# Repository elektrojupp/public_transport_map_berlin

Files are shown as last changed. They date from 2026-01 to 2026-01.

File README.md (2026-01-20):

# Public Transport Map of Berlin

There are some commercial maps of similar design out there. They mostly use multiple LEDs per station and show less complexity by splitting services into separate maps.

This project shows the complete maps for Berlin’s suburban rail and subway. It uses 312 NeoPixel-compatible RGB LEDs for 314 stations on a two-layer board. A standard ESP32 dev module is used to get live transport data. It will be replaced by a board supporting PSRAM for flexibility.

## PCB Design

The PCB design is done in KiCad 9. It uses SK6805-EC10-000 NeoPixel-compatible LEDs by OPSCO connected in one non-intersecting path.

The LEDs are only 1.1×1.1 mm in size and can be sourced from JLCPCB for PCB manufacturing and assembly.

The current PCB size is 153×107 mm, which is roughly the size of a DIN A6 sheet.

It is an improved but untested version of the original test design.

Scaling of the PCB can be done with a Python script. It includes automatic placement of the LEDs and routing in between. The scaled version only needs adjustment of the text size and placement of the ESP32 dev module connector.

## Software

The software is developed using VS Code, PlatformIO, and ESP-IDF. It is not documented, but the project can be compiled if you have a working setup.

It uses the REST API from derhuerst <https://github.com/derhuerst/bvg-rest> to get information about active rides on a certain suburban or subway line and displays the station where the train arrives next. It currently supports displaying only one line at a time due to a memory shortage.

### Features

- provisioning
- HTTP OTA server
- capacitive touch
- NeoPixel LED control
- display live train data

The HTTP OTA server is not secure and allows anyone to upload any firmware. It can be enabled by touching the "O" button during the startup sequence (blue blinking status LEDs). Similarly, provisioning data also gets removed.

## Scaling

The PCB has been designed to be minimal in size to reduce manufacturing cost. It can be scaled using the KiCad IPC API. This requires KiCad 9 and above. The IPC API has some quirks, but first it needs to be enabled in the KiCad settings.

## Pictures
Showing the actual version of the PCB:  

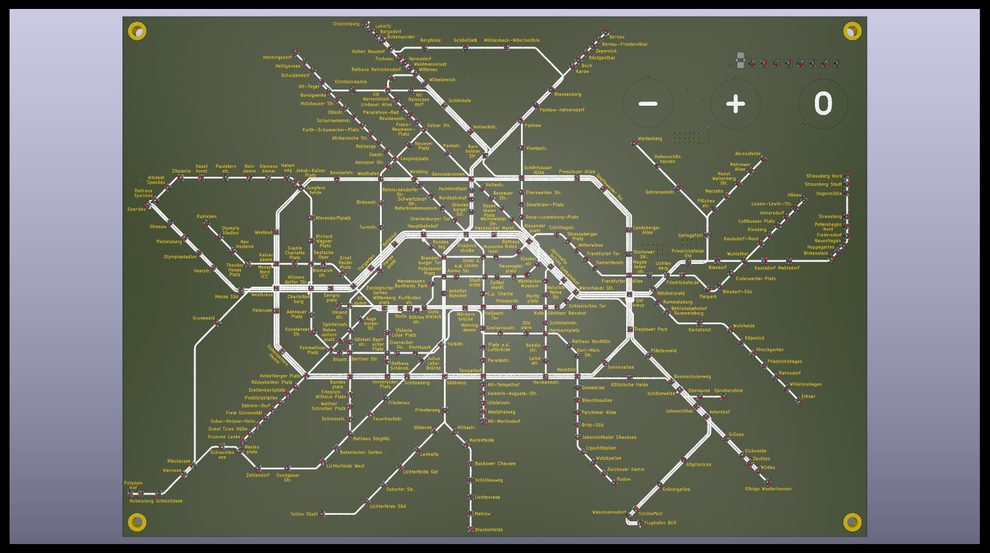
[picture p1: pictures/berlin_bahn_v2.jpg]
Berlin Bahn v2

V1 manufactured  

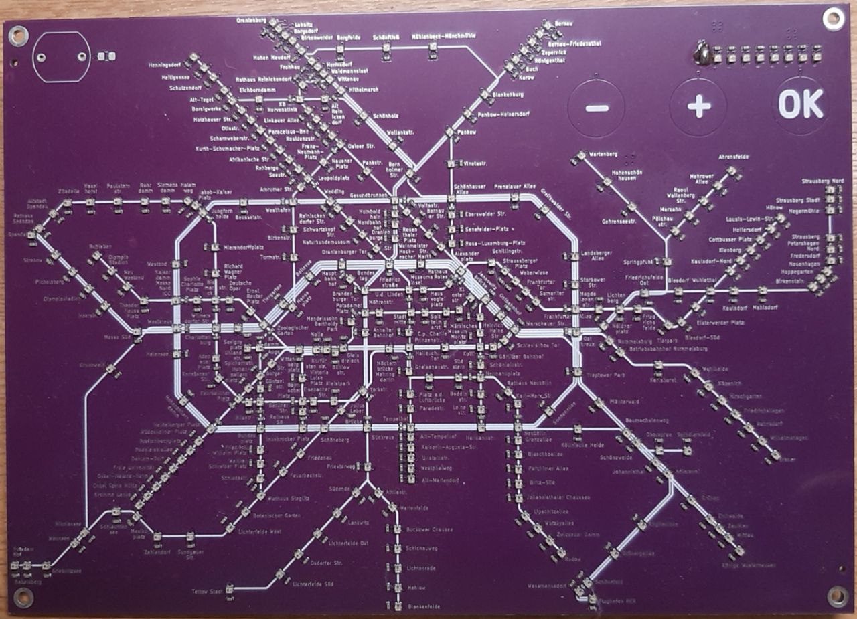
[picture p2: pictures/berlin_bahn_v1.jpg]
Berlin Bahn v1


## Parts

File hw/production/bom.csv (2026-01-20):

Designator | Footprint | Quantity | Value | LCSC Part #
C1, C10, C100, C101, C102, C103, C104, C105, C106, C107, C108, C109, C11, C110, C111, C112, C113, C114, C115, C116, C117, C118, C119, C12, C120, C121, C122, C123, C124, C125, C126, C127, C128, C129, C13, C130, C131, C132, C133, C134, C135, C136, C137, C138, C139, C14, C140, C141, C142, C143, C144, C145, C146, C147, C148, C149, C15, C150, C151, C152, C153, C154, C155, C156, C157, C158, C159, C16, C160, C161, C162, C163, C164, C165, C166, C167, C168, C169, C17, C170, C171, C172, C173, C174, C175, C176, C177, C178, C179, C18, C180, C181, C182, C183, C184, C185, C186, C187, C188, C189, C19, C190, C191, C192, C193, C194, C195, C196, C197, C198, C199, C2, C20, C200, C201, C202, C203, C204, C205, C206, C207, C208, C209, C21, C210, C211, C212, C213, C214, C215, C216, C217, C218, C219, C22, C220, C221, C222, C223, C224, C225, C226, C227, C228, C229, C23, C230, C231, C232, C233, C234, C235, C236, C237, C238, C239, C24, C240, C241, C242, C243, C244, C245, C246, C247, C248, C249, C25, C250, C251, C252, C253, C254, C255, C256, C257, C258, C259, C26, C260, C261, C262, C263, C264, C265, C266, C267, C268, C269, C27, C270, C271, C272, C273, C274, C275, C276, C277, C278, C279,C28, C280, C281, C282, C283, C284, C285, C286, C287, C288, C289, C29, C290, C291, C292, C293, C294, C295, C296, C297, C298, C299, C3, C30, C300, C301, C302, C303, C304, C305, C306, C307, C308, C309, C31, C310, C311, C312, C313, C314, C315, C316, C317, C318, C319, C32, C320, C33, C34, C35, C36, C37, C38, C39, C4, C40, C4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 | 0402 | 200 | 100n | C1525
U1, U10, U100, U101, U102, U103, U104, U105, U106, U107, U108, U109, U11, U110, U111, U112, U113, U114, U115, U116, U117, U118, U119, U12, U120, U121, U122, U123, U124, U125, U126, U127, U128, U129, U13, U130, U131, U132, U133, U134, U135, U136, U137, U138, U139, U14, U140, U141, U142, U143, U144, U145, U146, U147, U148, U149, U15, U150, U151, U152, U153, U154, U155, U156, U157, U158, U159, U16, U160, U161, U162, U163, U164, U165, U166, U167, U168, U169, U17, U170, U171, U172, U173, U174, U175, U176, U177, U178, U179, U18, U180, U181, U182, U183, U184, U185, U186, U187, U188, U189, U19, U190, U191, U192, U193, U194, U195, U196, U197, U198, U199, U2, U20, U200, U201, U202, U203, U204, U205, U206, U207, U208, U209, U21, U210, U211, U212, U213, U214, U215, U216, U217, U218, U219, U22, U220, U221, U222, U223, U224, U225, U226, U227, U228, U229, U23, U230, U231, U232, U233, U234, U235, U236, U237, U238, U239, U24, U240, U241, U242, U243, U244, U245, U246, U247, U248, U249, U25, U250, U251, U252, U253, U254, U255, U256, U257, U258, U259, U26, U260, U261, U262, U263, U264, U265, U266, U267, U268, U269, U27, U270, U271, U272, U273, U274, U275, U276, U277, U278, U279,U28, U280, U281, U282, U283, U284, U285, U286, U287, U288, U289, U29, U290, U291, U292, U293, U294, U295, U296, U297, U298, U299, U3, U30, U300, U301, U302, U303, U304, U305, U306, U307, U308, U309, U31, U310, U311, U312, U313, U314, U315, U316, U317, U318, U319, U32, U320, U33, U34, U35, U36, U37, U38, U39, U4, U40, U4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 | SMD-4P,1.1x1.1mm | 200 | XL-1010RGBC-WS2812B | C5349953

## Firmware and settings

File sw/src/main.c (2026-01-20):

#include "esp_system.h"
#include "esp_log.h"
#include "nvs_flash.h"
#include "esp_netif.h"
#include "esp_event.h"

#include "cap_touch.h"
#include "led.h"
#include "line_state.h"
#include "time_server.h"
#include "tripring.h"
#include "requests.h"
#include "provisioning.h"

//static const char * TAG = "APP_INIT";

static void cap_touch_task(void *pvParameters)
{
    // the first one runs until the init sequence is completed
    // enables to possibility to restart provisioning
    cap_touch_check();
    cap_touch_run();
}
static void led_task(void *pvParameters)
{
    display_chance_to_reset_provisioning_pattern();
    fiddle_as_lon_as_init();
    led_stripe_run();
}

static void http_request_task(void *pvParameters)
{
    BVG_run();
}


void app_main() 
{
    esp_log_level_set("esp-x509-crt-bundle", ESP_LOG_ERROR);
    esp_log_level_set("BVG_FETCHER", ESP_LOG_VERBOSE);
    
    line_state_init();
    line_state_set_init_mode();
    led_stripe_init();
    cap_touch_init();
    tr_init();

    // got into the check if provisioning can be reset mode
    line_state_set_reset_provisioning_mode();
    xTaskCreatePinnedToCore(cap_touch_task, "cap_touch_task", 4096, NULL, 5, NULL, 1);

    xTaskCreatePinnedToCore(cap_touch_task, "cap_touch_task", 4096, NULL, 5, NULL, 1);
    xTaskCreatePinnedToCore(http_request_task, "http_request_task", 8192, NULL, 5, NULL, 0);
    xTaskCreatePinnedToCore(led_task, "led_task", 4096, NULL, 5, NULL, 1);

    // wait init sequence
    vTaskDelay(pdMS_TO_TICKS(3000));
    line_state_release_reset_provisioning_mode();

    // wait for 3 seconds while displaying key pattern to indicate that credentials can be deleted
    bool reset = cap_touch_check_is_pressed();
    provisioning(reset);
    
    time_server();
    print_time();

    line_state_release_init_mode();
}

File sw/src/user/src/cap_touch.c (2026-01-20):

#include <stdio.h>
#include <inttypes.h>
#include "freertos/FreeRTOS.h"
#include "freertos/task.h"
#include "esp_log.h"
#include "esp_timer.h"
#include "driver/touch_sens.h"
#include "line_state.h"
#include "line_data.h"

typedef enum {
    TSTATE_RELEASED = 0,
    TSTATE_PENDING_ACTIVE,
    TSTATE_ACTIVE,
    TSTATE_PENDING_RELEASE
} tstate_t;

typedef struct {
    touch_channel_handle_t ch;
    uint32_t               baseline;
    uint32_t               thresh_abs;       // V1 uses absolute threshold (baseline * (1 - ratio))
    tstate_t               st;
    int64_t                dwell_start_us;
} tdebounce_t;

#define TOUCH_NUM_CHANNELS       3
#define TOUCH_THRESH_RATIO       0.20f   // trigger when value drops 20% from baseline
#define TOUCH_ACTIVE_DWELL_MS    60      // must stay below threshold this long to count as "touched"
#define TOUCH_RELEASE_DWELL_MS   60      // must stay above threshold this long to count as "released"
#define TOUCH_POLL_PERIOD_MS     10      // sampling period of the poll task

/*
   T0=GPIO4,  T1=GPIO0,  T2=GPIO2,  T3=GPIO15, T4=GPIO13,
   T5=GPIO12, T6=GPIO14, T7=GPIO27, T8=GPIO33, T9=GPIO32   */
static const int s_touch_chan_ids[TOUCH_NUM_CHANNELS] = { 0, 3, 6};

static touch_sensor_handle_t s_touch = NULL;
static tdebounce_t s_db[TOUCH_NUM_CHANNELS] = {0};

// pressed is used to indicate if some button has been pressed and released during the initalization phase
// and to check weather or not delete previously saved wifi credentials
uint32_t check_pressed = 0;

static const char *TAG = "CAPACITIVE_TOUCH";

void on_touch(int chan_id) {
    if (chan_id == 3) {
        (void)line_state_add_wrap(+1, 0, line_data_number_of_lines()-1);
    } else if (chan_id == 0) {
        (void)line_state_add_wrap(-1, 0, line_data_number_of_lines()-1);
    }
    line_state_set_pressed(true);
    line_state_t s;
    line_state_get(&s);
    ESP_LOGI(TAG, "line = %d pressed = %d, channel = %d", s.line, s.pressed, chan_id);
}

void on_release(int chan_id) {
    line_state_set_pressed(false);
    line_state_t s;
    line_state_get(&s);
    ESP_LOGI(TAG, "line = %d, pressed = %d, channel = %d", s.line, s.pressed, chan_id);
}

void cap_touch_init(void)
{
    ESP_LOGI(TAG, "INIT");
    ESP_LOGI(TAG, "Channels = T%d, T%d, T%d", s_touch_chan_ids[0], s_touch_chan_ids[1], s_touch_chan_ids[2]);

    touch_sensor_sample_config_t sample_cfg[] = {
        TOUCH_SENSOR_V1_DEFAULT_SAMPLE_CONFIG(5.0, TOUCH_VOLT_LIM_L_0V5, TOUCH_VOLT_LIM_H_1V7),
    };
    touch_sensor_config_t sens_cfg = TOUCH_SENSOR_DEFAULT_BASIC_CONFIG(1, sample_cfg);
    ESP_ERROR_CHECK(touch_sensor_new_controller(&sens_cfg, &s_touch));

    touch_sensor_filter_config_t filter_cfg = TOUCH_SENSOR_DEFAULT_FILTER_CONFIG();
    ESP_ERROR_CHECK(touch_sensor_config_filter(s_touch, &filter_cfg));

    touch_channel_config_t ch_base_cfg = {
        .abs_active_thresh = {1000},
        .charge_speed      = TOUCH_CHARGE_SPEED_3,
        .init_charge_volt  = TOUCH_INIT_CHARGE_VOLT_DEFAULT,
        .group             = TOUCH_CHAN_TRIG_GROUP_BOTH,
    };

    // create a channel for each pin
    for (int i = 0; i < TOUCH_NUM_CHANNELS; i++) {
        ESP_ERROR_CHECK(touch_sensor_new_channel(s_touch, s_touch_chan_ids[i], &ch_base_cfg, &s_db[i].ch));
        s_db[i].st = TSTATE_RELEASED;
        s_db[i].dwell_start_us = 0;
    }

    uint32_t vals[TOUCH_NUM_CHANNELS] = {0};
    uint32_t scans = 100;

    // start touch sensor
    ESP_ERROR_CHECK(touch_sensor_enable(s_touch));
    // make a few readings for sensor to settle
    for (int i = 0; i < scans; i++) {
        ESP_ERROR_CHECK(touch_sensor_trigger_oneshot_scanning(s_touch, 2000));
        for (int j = 0; j < TOUCH_NUM_CHANNELS; j++) {
            uint32_t val = 0;
            ESP_ERROR_CHECK(touch_channel_read_data(s_db[j].ch, TOUCH_CHAN_DATA_TYPE_SMOOTH, &val));
        }
    }
    ESP_ERROR_CHECK(touch_sensor_disable(s_touch));

    // start touch sensor
    ESP_ERROR_CHECK(touch_sensor_enable(s_touch));
    // scan to get the mean value
    for (int i = 0; i < scans; i++) {
        ESP_ERROR_CHECK(touch_sensor_trigger_oneshot_scanning(s_touch, 2000));
        for (int j = 0; j < TOUCH_NUM_CHANNELS; j++) {
            uint32_t val = 0;
            ESP_ERROR_CHECK(touch_channel_read_data(s_db[j].ch, TOUCH_CHAN_DATA_TYPE_SMOOTH, &val));
            vals[j] += val;
        }
    }
    ESP_ERROR_CHECK(touch_sensor_disable(s_touch));

    // compute mean and threshold for the sensor
    for(int i = 0; i < TOUCH_NUM_CHANNELS; i ++) {
        vals[i] /= scans;
        s_db[i].baseline  = vals[i];
        s_db[i].thresh_abs = (uint32_t)(vals[i] * (1.0f - TOUCH_THRESH_RATIO));
        //ch_base_cfg.abs_active_thresh[i] = s_db[i].thresh_abs;
        // do i need to do this ??? lets test
        //ESP_ERROR_CHECK(touch_sensor_reconfig_channel(s_db[i].ch, &ch_base_cfg));
        ESP_LOGI(TAG, "T%d mean reading = %d, threshold = %d", s_touch_chan_ids[0], s_db[i].baseline, s_db[i].thresh_abs);
    }

    // Start continuous scanning
    ESP_ERROR_CHECK(touch_sensor_enable(s_touch));
    ESP_ERROR_CHECK(touch_sensor_start_continuous_scanning(s_touch));
}
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
